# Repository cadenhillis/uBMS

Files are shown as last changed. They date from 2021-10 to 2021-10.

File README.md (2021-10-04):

# uBMS
A tiny BMS to plug into things

I used this to plug into my uVU board, but it coulld be used for other things. A regular micro-B USB plugs in and charges it, and the little BMS chip and a boost supply do the rest for the 5V output.

I didn't get too long of a battery life from this into the uVU, but that isn't designed to be ultra low power anyways.

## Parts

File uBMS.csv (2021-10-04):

Source: | E:\Projects\8. Micro VU Meter and BMS\uBMS\uBMS.sch
Date: | 6/15/2021 8:16:16 PM
Tool: | Eeschema (5.1.9)-1
Generator: | C:\Program Files\KiCad\bin\scripting\plugins/bom_csv_grouped_by_value.py
Component Count: | 21
Individual Components:
Item | Qty | Reference(s) | Value | LibPart | Footprint | Datasheet
 |  | BT1 | LP851719JU + PCM + 2 WIRES 50MM 210MAH | Device:Battery_Cell | My_Library:LP851719JU | ~
 |  | C1 | 22uF | Device:C | Resistor_SMD:R_0805_2012Metric | LMK212BBJ226MG-T
 |  | C2 | 4.7uF | Device:C | Capacitor_SMD:C_0805_2012Metric | CL21A475KPFNNNE
 |  | C3 | 22uF | Device:C | Resistor_SMD:R_0805_2012Metric | LMK212BBJ226MG-T
 |  | C4 | 22uF | Device:C | Resistor_SMD:R_0805_2012Metric | LMK212BBJ226MG-T
 |  | D1 | DF2B7AFU,H3F | Device:D_TVS | Diode_SMD:D_SOD-323_HandSoldering | ~
 |  | H1 | M2 | Mechanical:MountingHole | MountingHole:MountingHole_2.2mm_M2 | ~
 |  | H2 | M2 | Mechanical:MountingHole | MountingHole:MountingHole_2.2mm_M2 | ~
 |  | J1 | TSW-102-07-T-S | Connector_Generic:Conn_01x02 | Connector_PinHeader_2.54mm:PinHeader_1x02_P2.54mm_Vertical | ~
 |  | J2 | 10103594-0001LF | Connector:USB_B_Micro | Connector_USB:USB_Micro-B_Amphenol_10103594-0001LF_Horizontal | 10103594-0001LF
 |  | L1 | 2.2uH | Device:L | Inductor_SMD:L_Taiyo-Yuden_NR-24xx_HandSoldering | NRH2412T2R2MNGH
 |  | LED1 | Red | Device:LED | LED_SMD:LED_0603_1608Metric | 150060RS55040
 |  | LED2 | Green | Device:LED | LED_SMD:LED_0603_1608Metric | 150060VS55040
 |  | R1 | 5k | Device:R_US | Resistor_SMD:R_0603_1608Metric | ~
 |  | R2 | 680 | Device:R_US | Resistor_SMD:R_0603_1608Metric | ~
 |  | R3 | 10R | Device:R_US | Resistor_SMD:R_0603_1608Metric | ~
 |  | R4 | 680 | Device:R_US | Resistor_SMD:R_0603_1608Metric | ~
 |  | R5 | 10k | Device:R_US | Resistor_SMD:R_0603_1608Metric | ~
 |  | U1 | LM66100 | My_Library:LM66100 | My_Library:SC70-6 | LM66100DCKR
 |  | U2 | MCP73831T-2ACI/OT | Battery_Management:MCP73832-2-OT | Package_TO_SOT_SMD:SOT-23-5 | http://ww1.microchip.com/downloads/en/DeviceDoc/20001984g.pdf
 |  | U3 | TPS613223ADBVT | Regulator_Switching:TPS613223ADBV | Package_TO_SOT_SMD:SOT-23-5 | http://www.ti.com/lit/ds/symlink/tps61322.pdf
Collated Components:
Item | Qty | Reference(s) | Value | LibPart | Footprint | Datasheet
1 | 1 | BT1 | LP851719JU + PCM + 2 WIRES 50MM 210MAH | Device:Battery_Cell | My_Library:LP851719JU | ~
2 | 3 | C1, C3, C4 | 22uF | Device:C | Resistor_SMD:R_0805_2012Metric | LMK212BBJ226MG-T
3 | 1 | C2 | 4.7uF | Device:C | Capacitor_SMD:C_0805_2012Metric | CL21A475KPFNNNE
4 | 1 | D1 | DF2B7AFU,H3F | Device:D_TVS | Diode_SMD:D_SOD-323_HandSoldering | ~
5 | 2 | H1, H2 | M2 | Mechanical:MountingHole | MountingHole:MountingHole_2.2mm_M2 | ~
6 | 1 | J1 | TSW-102-07-T-S | Connector_Generic:Conn_01x02 | Connector_PinHeader_2.54mm:PinHeader_1x02_P2.54mm_Vertical | ~
7 | 1 | J2 | 10103594-0001LF | Connector:USB_B_Micro | Connector_USB:USB_Micro-B_Amphenol_10103594-0001LF_Horizontal | 10103594-0001LF
8 | 1 | L1 | 2.2uH | Device:L | Inductor_SMD:L_Taiyo-Yuden_NR-24xx_HandSoldering | NRH2412T2R2MNGH
9 | 1 | LED1 | Red | Device:LED | LED_SMD:LED_0603_1608Metric | 150060RS55040
10 | 1 | LED2 | Green | Device:LED | LED_SMD:LED_0603_1608Metric | 150060VS55040
11 | 1 | R1 | 5k | Device:R_US | Resistor_SMD:R_0603_1608Metric | ~
12 | 2 | R2, R4 | 680 | Device:R_US | Resistor_SMD:R_0603_1608Metric | ~
13 | 1 | R3 | 10R | Device:R_US | Resistor_SMD:R_0603_1608Metric | ~
14 | 1 | R5 | 10k | Device:R_US | Resistor_SMD:R_0603_1608Metric | ~
15 | 1 | U1 | LM66100 | My_Library:LM66100 | My_Library:SC70-6 | LM66100DCKR
16 | 1 | U2 | MCP73831T-2ACI/OT | Battery_Management:MCP73832-2-OT | Package_TO_SOT_SMD:SOT-23-5 | http://ww1.microchip.com/downloads/en/DeviceDoc/20001984g.pdf
17 | 1 | U3 | TPS613223ADBVT | Regulator_Switching:TPS613223ADBV | Package_TO_SOT_SMD:SOT-23-5 | http://www.ti.com/lit/ds/symlink/tps61322.pdf

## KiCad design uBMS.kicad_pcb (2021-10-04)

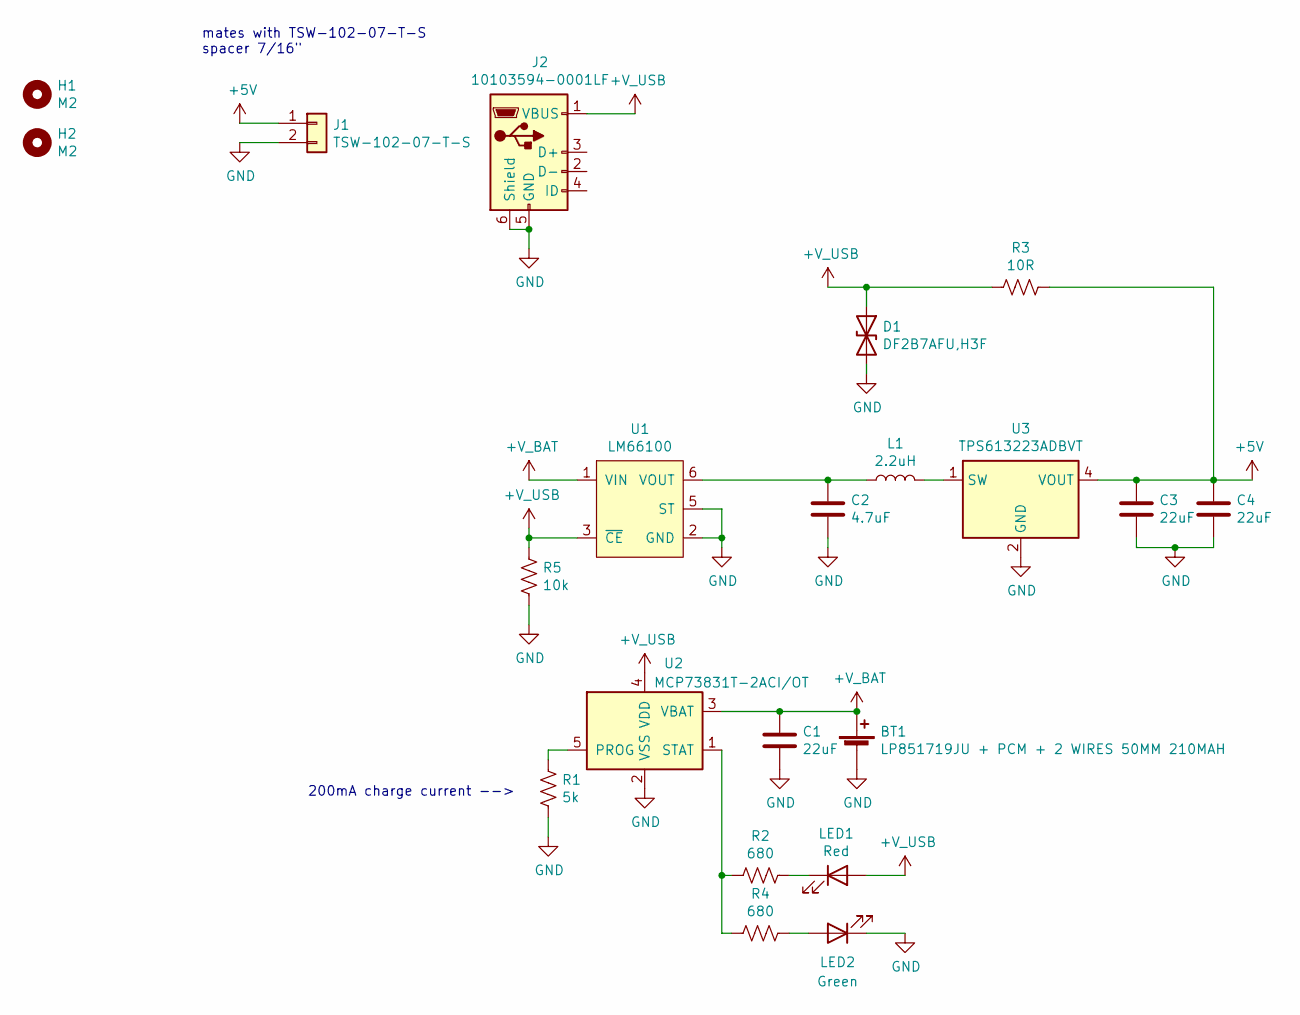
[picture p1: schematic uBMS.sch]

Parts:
BT1: LP851719JU + PCM + 2 WIRES 50MM 210MAH; LP851719JU
C1, C3, C4: 22uF; R_0805_2012Metric
C2: 4.7uF; C_0805_2012Metric
D1: DF2B7AFU,H3F; D_SOD-323_HandSoldering
H1, H2: M2; MountingHole_2.2mm_M2
J1: TSW-102-07-T-S; PinHeader_1x02_P2.54mm_Vertical
J2: 10103594-0001LF; USB_Micro-B_Amphenol_10103594-0001LF_Horizontal
L1: 2.2uH; L_Taiyo-Yuden_NR-24xx_HandSoldering
LED1: Red; LED_0603_1608Metric
LED2: Green; LED_0603_1608Metric
R1: 5k; R_0603_1608Metric
R2, R4: 680; R_0603_1608Metric
R3: 10R; R_0603_1608Metric
R5: 10k; R_0603_1608Metric
U1: LM66100; SC70-6
U2: MCP73831T-2ACI/OT; SOT-23-5
U3: TPS613223ADBVT; SOT-23-5

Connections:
+5V: C3.1, C4.1, J1.1, R3.1, U3.4 (VOUT)
+V_BAT: BT1.1 (+), C1.1, U1.1 (VIN), U2.3 (VBAT)
+V_USB: D1.1 (A1), J2.1 (VBUS), LED1.2 (A), R3.2, R5.1, U1.3 (~CE), U2.4 (VDD)
GND: BT1.2 (-), C1.2, C2.2, C3.2, C4.2, D1.2 (A2), J1.2, J2.5 (GND), J2.6 (Shield), LED2.1 (K), R1.2, R5.2, U1.2 (GND), U1.5 (ST), U2.2 (VSS), U3.2 (GND)
unnamed: C2.1, L1.1, U1.6 (VOUT)
unnamed: L1.2, U3.1 (SW)
unnamed: LED1.1 (K), R2.1
unnamed: LED2.2 (A), R4.1
unnamed: R1.1, U2.5 (PROG)
unnamed: R2.2, R4.2, U2.1 (STAT)

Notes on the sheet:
200mA charge current -->
mates with TSW-102-07-T-S spacer 7/16"

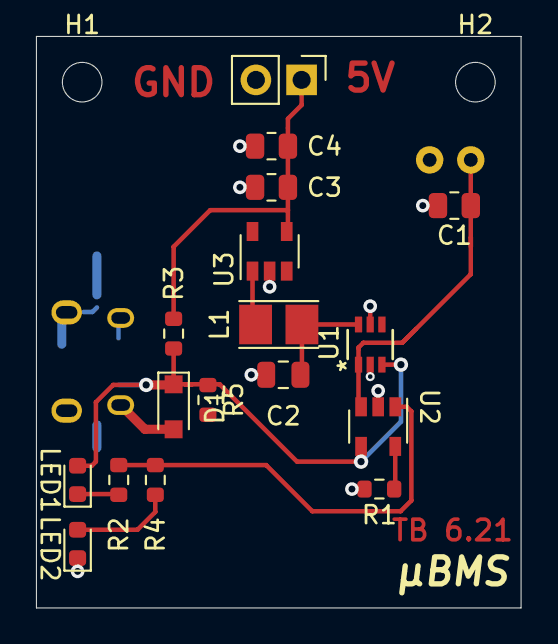
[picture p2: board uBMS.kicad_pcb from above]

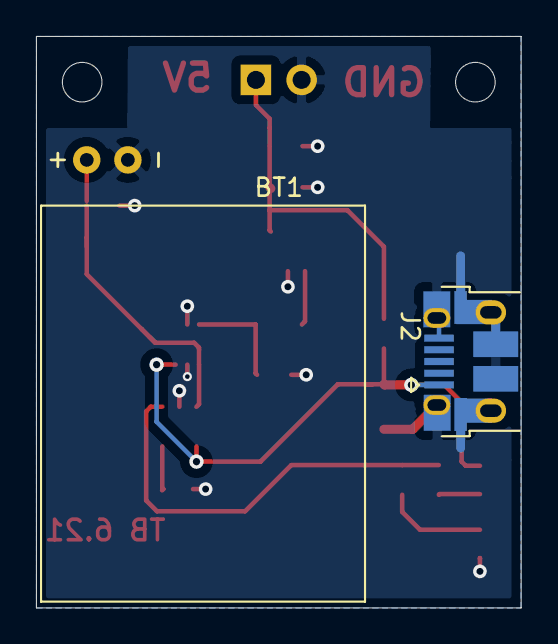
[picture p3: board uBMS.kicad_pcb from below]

Board: 2 copper layers, 26.9 x 31.8 mm, 21 parts (2 on the bottom side), 10 nets.

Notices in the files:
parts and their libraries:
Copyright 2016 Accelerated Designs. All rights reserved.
